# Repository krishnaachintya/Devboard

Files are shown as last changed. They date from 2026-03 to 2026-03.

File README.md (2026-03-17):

# Devboard.csv

my custom devboard :)

has debug leds and a 9-DOF IMU composed of multiple 3-axis sensors

in the format of a rpi pico



# BOM

| Id | Designator | Quantity | Comment | Price (USD) |
| -- | --- | --- | --- | --- |
| 1  | R5,R7 | 2 | 1K | $1 |
| 2  | C16,C15 | 2 | 33pF | $1 |
| 3  | C10,C11,C5,C8,C3,C2,C7,C6,C4,C17,C1,C20,C18 | 13 | 0.1uF | $3 |
| 4  | D3,D1,D2 | 3 | LED | $2 |
| 5  | Y1 | 1 | 12MHz Crystal | $2 |
| 6  | R10,R9,R8 | 3 | 680Ω | $1 |
| 7  | J4 | 1 | Conn_01x03 | $1 |
| 8  | C9,C12 | 2 | 1uF | $1 |
| 9  | U1 | 1 | RP2040 | $2 |
| 10 | R4,R3 | 2 | 27Ω | $1 |
| 11 | U3 | 1 | W25Q128JVS Flash | $2 |
| 12 | J3,J2 | 2 | Conn_01x20 Headers | $3 |
| 13 | C21 | 1 | 2.2uF | $1 |
| 14 | C13,C14 | 2 | 10uF | $4 |
| 15 | U4 | 1 | ICM-20602 IMU | $12 |
| 16 | U2 | 1 | MCP1700 3.3V Regulator | $1 |
| 17 | J1 | 1 | USB-C Connector | $3 |
| 18 | SW1 | 1 | Push Button | $1 |
| 19 | R6 | 1 | 10K | $1 |
| 20 | R2,R1 | 2 | 5.1K | $1 |
| 21 | C19 | 1 | 10nF | $1 |
| 22 | Total | | | $45 including shipping|

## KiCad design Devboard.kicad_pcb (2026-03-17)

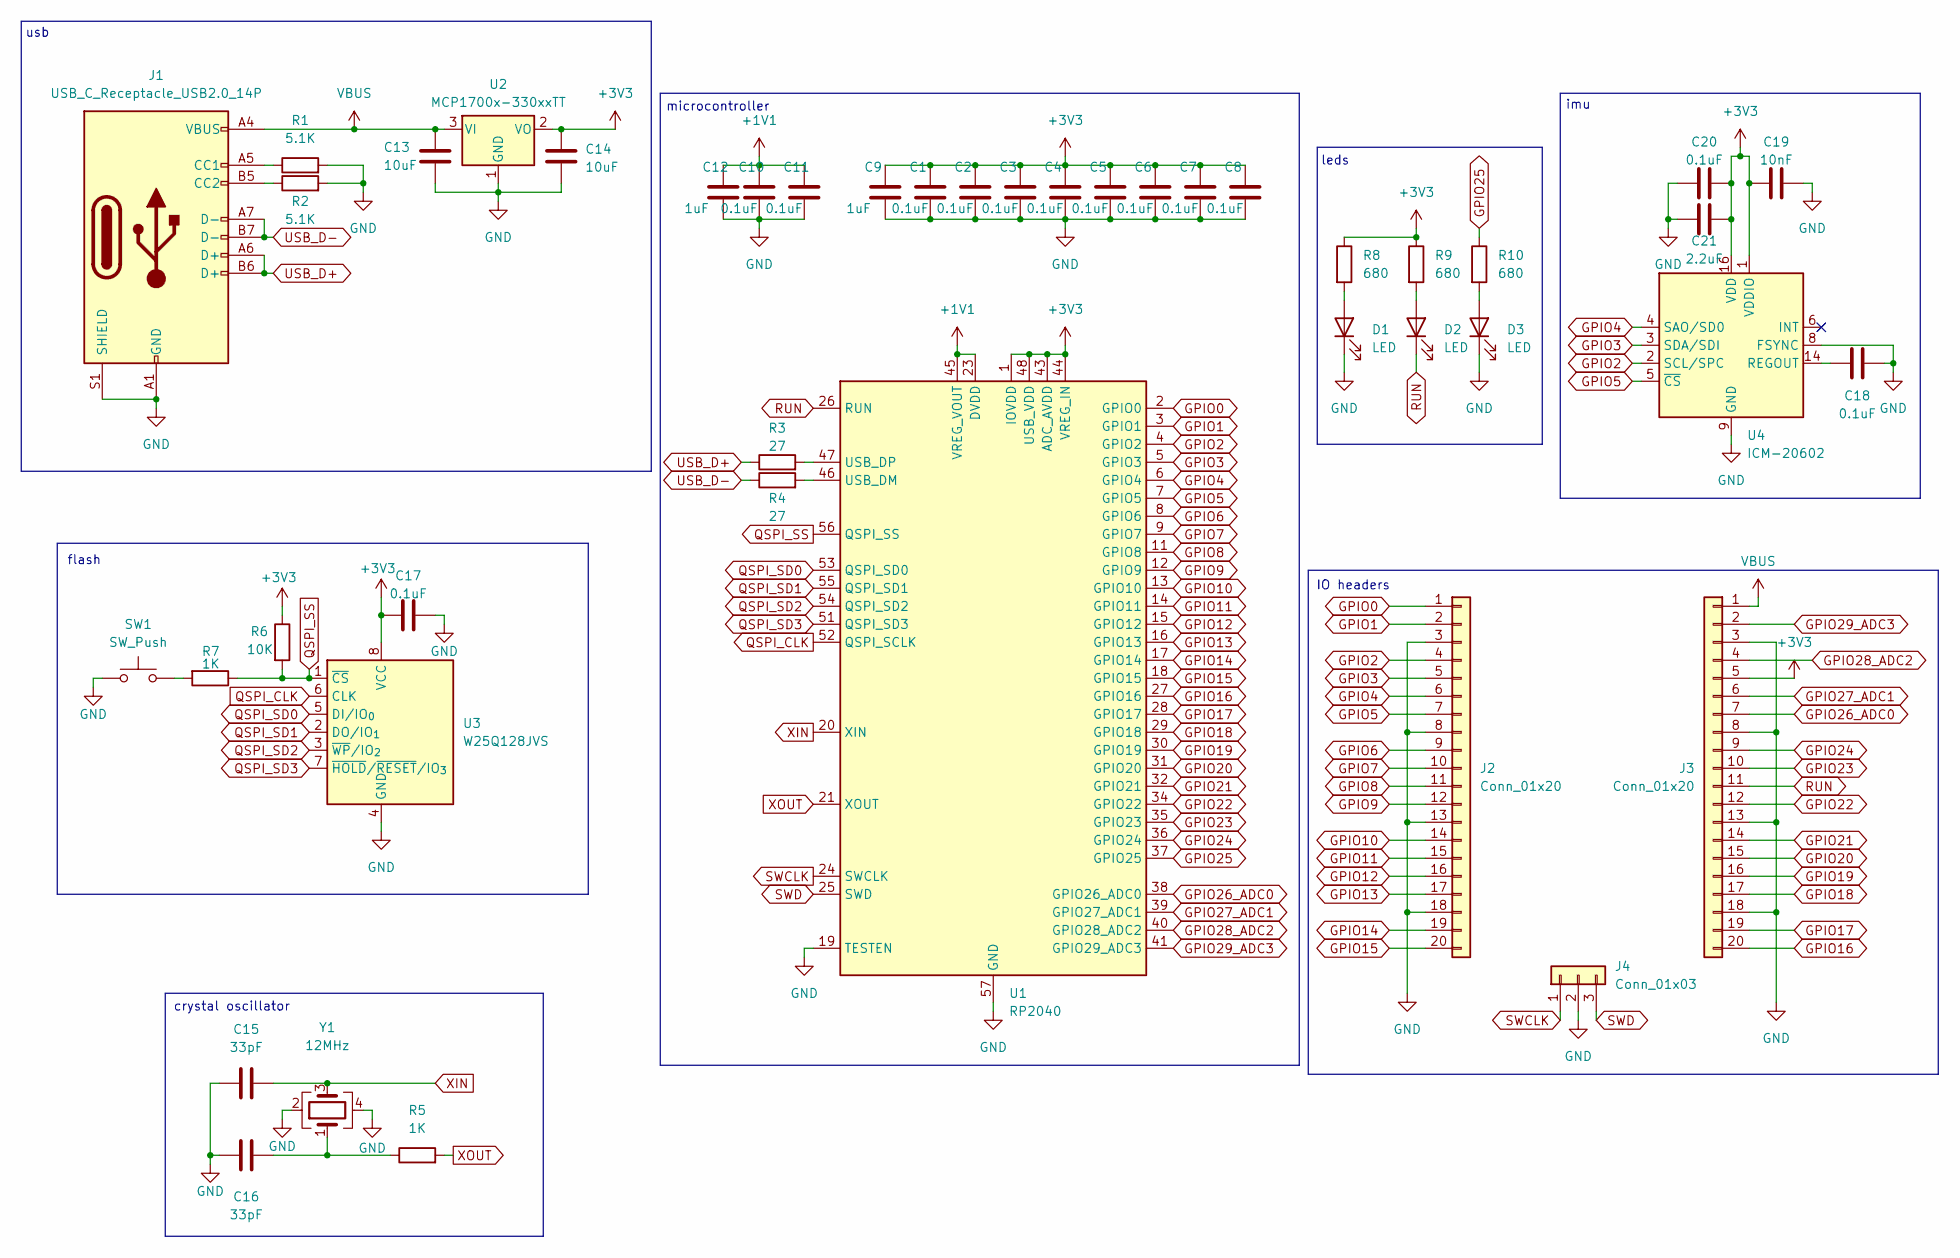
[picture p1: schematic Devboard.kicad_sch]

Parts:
C1, C2, C3, C4, C5, C6, C7, C8, C10, C11, C17, C18, C20: 0.1uF; C_0402_1005Metric
C9, C12: 1uF; C_0402_1005Metric
C13, C14: 10uF; C_0603_1608Metric
C15, C16: 33pF; C_0402_1005Metric
C19: 10nF; C_0402_1005Metric
C21: 2.2uF; C_0402_1005Metric
D1, D2, D3: LED; LED_0603_1608Metric
J1: USB_C_Receptacle_USB2.0_14P; USB_C_Receptacle_HRO_TYPE-C-31-M-12
J2, J3: Conn_01x20; PinHeader_1x20_P2.54mm_Vertical
J4: Conn_01x03; PinHeader_1x03_P2.54mm_Vertical
R1, R2: 5.1K; R_0402_1005Metric
R3, R4: 27; R_0402_1005Metric
R5, R7: 1K; R_0402_1005Metric
R6: 10K; R_0402_1005Metric
R8, R9, R10: 680; R_0402_1005Metric
SW1: SW_Push; SW_Push_SPST_NO_Alps_SKRK
U1: RP2040; QFN-56-1EP_7x7mm_P0.4mm_EP3.2x3.2mm
U2: MCP1700x-330xxTT; SOT-23
U3: W25Q128JVS; Winbond_USON-8-1EP_3x2mm_P0.5mm_EP0.2x1.6mm
U4: ICM-20602; LGA-16_3x3mm_P0.5mm_LayoutBorder3x5y
Y1: 12MHz; Crystal_SMD_3225-4Pin_3.2x2.5mm

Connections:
+1V1: C10.1, C11.1, C12.1, U1.23 (DVDD), U1.45 (VREG_VOUT), U1.50 (DVDD)
+3V3: C1.1, C2.1, C3.1, C4.1, C5.1, C6.1, C7.1, C8.1, C9.1, C14.1, C17.1, C19.1, C20.2, C21.2, J3.5, R6.1, R8.1, R9.1, U1.1 (IOVDD), U1.10 (IOVDD), U1.22 (IOVDD), U1.33 (IOVDD), U1.42 (IOVDD), U1.43 (ADC_AVDD), U1.44 (VREG_IN), U1.48 (USB_VDD), U1.49 (IOVDD), U2.2 (VO), U3.8 (VCC), U4.1 (VDDIO), U4.16 (VDD)
GND: C1.2, C2.2, C3.2, C4.2, C5.2, C6.2, C7.2, C8.2, C9.2, C10.2, C11.2, C12.2, C13.2, C14.2, C15.1, C16.1, C17.2, C18.2, C19.2, C20.1, C21.1, D1.1 (K), D3.1 (K), J1.A1 (GND), J1.A12 (GND), J1.B1 (GND), J1.B12 (GND), J1.S1 (SHIELD), J2.3, J2.8, J2.13, J2.18, J3.3, J3.8, J3.13, J3.18, J4.2, R1.2, R2.2, SW1.1, U1.19 (TESTEN), U1.57 (GND), U2.1 (GND), U3.4 (GND), U4.8 (FSYNC), U4.9 (GND), U4.10 (GND), U4.11 (GND), U4.12 (GND), U4.13 (GND), U4.15 (GND), Y1.2, Y1.4
GPIO0: J2.1, U1.2 (GPIO0)
GPIO1: J2.2, U1.3 (GPIO1)
GPIO2: J2.4, U1.4 (GPIO2), U4.2 (SCL/SPC)
GPIO3: J2.5, U1.5 (GPIO3), U4.3 (SDA/SDI)
GPIO4: J2.6, U1.6 (GPIO4), U4.4 (SAO/SD0)
GPIO5: J2.7, U1.7 (GPIO5), U4.5 (~CS)
GPIO6: J2.9, U1.8 (GPIO6)
GPIO7: J2.10, U1.9 (GPIO7)
GPIO8: J2.11, U1.11 (GPIO8)
GPIO9: J2.12, U1.12 (GPIO9)
GPIO10: J2.14, U1.13 (GPIO10)
GPIO11: J2.15, U1.14 (GPIO11)
GPIO12: J2.16, U1.15 (GPIO12)
GPIO13: J2.17, U1.16 (GPIO13)
GPIO14: J2.19, U1.17 (GPIO14)
GPIO15: J2.20, U1.18 (GPIO15)
GPIO16: J3.20, U1.27 (GPIO16)
GPIO17: J3.19, U1.28 (GPIO17)
GPIO18: J3.17, U1.29 (GPIO18)
GPIO19: J3.16, U1.30 (GPIO19)
GPIO20: J3.15, U1.31 (GPIO20)
GPIO21: J3.14, U1.32 (GPIO21)
GPIO22: J3.12, U1.34 (GPIO22)
GPIO23: J3.10, U1.35 (GPIO23)
GPIO24: J3.9, U1.36 (GPIO24)
GPIO25: R10.1, U1.37 (GPIO25)
GPIO26_ADC0: J3.7, U1.38 (GPIO26_ADC0)
GPIO27_ADC1: J3.6, U1.39 (GPIO27_ADC1)
GPIO28_ADC2: J3.4, U1.40 (GPIO28_ADC2)
GPIO29_ADC3: J3.2, U1.41 (GPIO29_ADC3)
unnamed: C16.2, R5.1, Y1.1
unnamed: D1.2 (A), R8.2
unnamed: D2.2 (A), R9.2
unnamed: D3.2 (A), R10.2
unnamed: J1.A5 (CC1), R1.1
unnamed: J1.B5 (CC2), R2.1
unnamed: R7.2, SW1.2
unnamed: R4.2, U1.46 (USB_DM)
unnamed: R3.2, U1.47 (USB_DP)
unnamed: C18.1, U4.14 (REGOUT)
QSPI_CLK: U1.52 (QSPI_SCLK), U3.6 (CLK)
QSPI_SD0: U1.53 (QSPI_SD0), U3.5 (DI/IO_{0})
QSPI_SD1: U1.55 (QSPI_SD1), U3.2 (DO/IO_{1})
QSPI_SD2: U1.54 (QSPI_SD2), U3.3 (~WP/IO_{2})
QSPI_SD3: U1.51 (QSPI_SD3), U3.7 (~HOLD/~RESET/IO_{3})
QSPI_SS: R6.2, R7.1, U1.56 (QSPI_SS), U3.1 (~CS)
RUN: D2.1 (K), J3.11, U1.26 (RUN)
SWCLK: J4.1, U1.24 (SWCLK)
SWD: J4.3, U1.25 (SWD)
USB_D+: J1.A6 (D+), J1.B6 (D+), R3.1
USB_D-: J1.A7 (D-), J1.B7 (D-), R4.1
VBUS: C13.1, J1.A4 (VBUS), J1.A9 (VBUS), J1.B4 (VBUS), J1.B9 (VBUS), J3.1, U2.3 (VI)
XIN: C15.2, U1.20 (XIN), Y1.3
XOUT: R5.2, U1.21 (XOUT)

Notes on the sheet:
usb
imu
leds
flash
crystal oscillator
microcontroller
IO headers

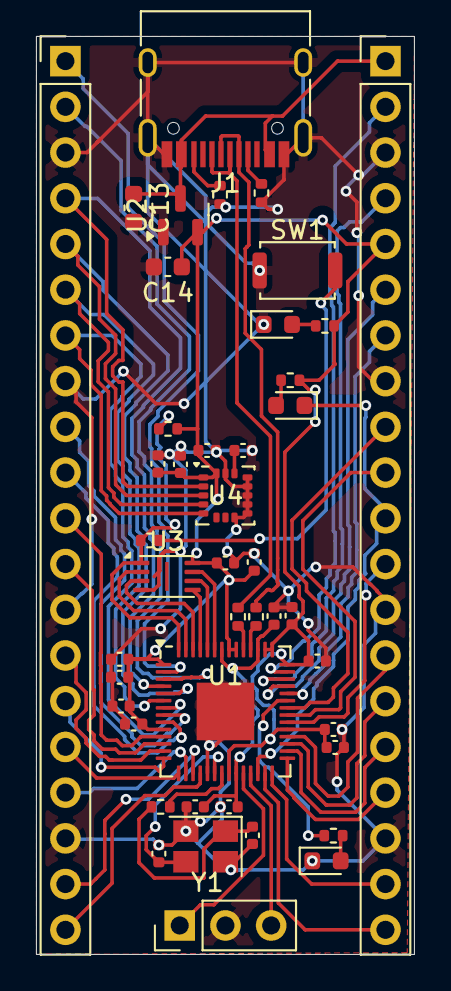
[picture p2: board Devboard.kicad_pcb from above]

Board: 2 copper layers, 21.0 x 51.0 mm, 44 parts (0 on the bottom side), 57 nets.
